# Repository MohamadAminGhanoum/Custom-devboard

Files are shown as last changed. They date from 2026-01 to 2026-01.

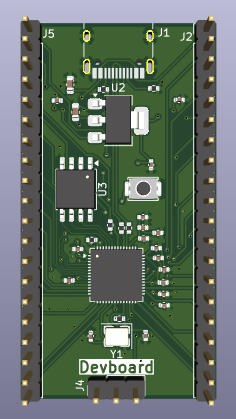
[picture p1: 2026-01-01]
assets/Screenshot 2026-01-01 at 15.13.54.png

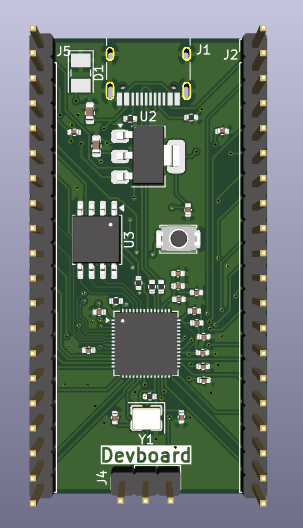
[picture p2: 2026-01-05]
assets/Final 3d model.png

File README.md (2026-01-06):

# Custom-devboard
I will make custom devboard that i can use to create simple projects on my breadboard that do not require soldering. these projects could e.g be make light blink and control simple sensors. 

 

During this hour, i worked on beginning with the set up of schematic. I followed the guide and learned new things, e.g about the decoupling capacitors and how they function in the circuit. I also learned about how the usb-c is connected in a circuit and what the different pins do.



The finished schematic diagram looks like this:



Then i began building and connecting components  pcb i have built:
The pcb i did was the most complex i have done so far, it was soo tricky because of the small space, especially when connecting to the rp2040 mcu. As seen in this picture, it was difficult to conenct som tracks in such a small spacing, so i had to do a lot of changes to achieve the ending result.




But now, i think the more complex part is here, i have 42 errors i should fix This actually takes a lot of time.



I got to fix all vital errors and ended only with the silkscreen crossing the edgecuts, and this error is normal, because i want the usb-c to go past the board-ending, so it does not matter, however the finished look for pcb looks like this:



The BOM:

Screenshot_1-1-2026_204322_docs google com

LCSC Electronics:

Screenshot_5-1-2026_164121_www lcsc com

JLCPCB:



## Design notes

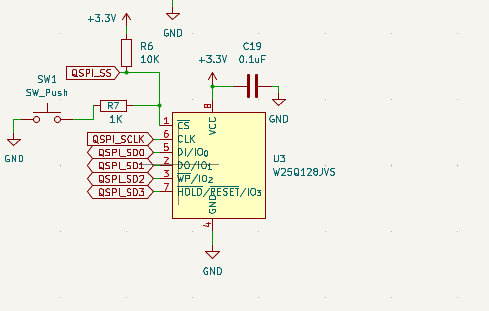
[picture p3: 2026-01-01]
assets/Schematic-4.png

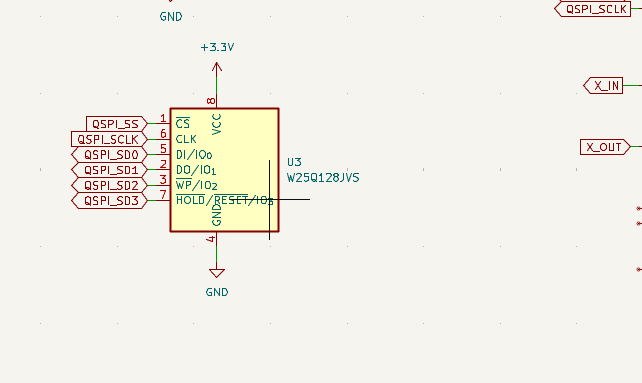
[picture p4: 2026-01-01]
assets/schematic-3.png

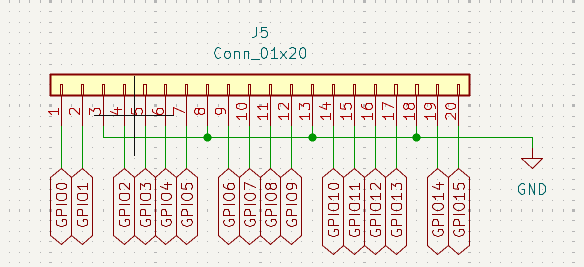
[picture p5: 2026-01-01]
assets/Schematic-7.png

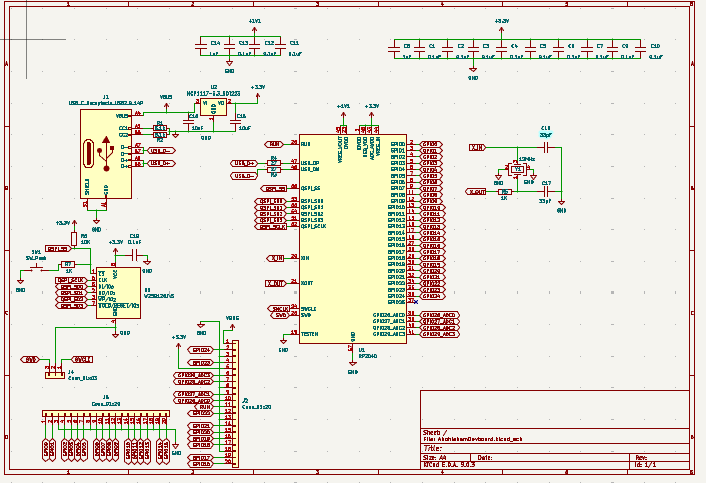
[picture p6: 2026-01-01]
assets/Schematic-8.png

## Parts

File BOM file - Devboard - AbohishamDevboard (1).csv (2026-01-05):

Id | Designator | Footprint | Quantity | Comment | LCSC part: | Quantity from LCSC electronics | Price from LCSC
1 | C19,C3,C10,C4,C11,C1,C12,C7,C5,C2,C13,C6,C9 | C_0402_1005Metric | 13 | 0.1uF | C1525 | 100 | 0.12 USD
2 | C17,C18 | C_0402_1005Metric | 2 | 33pF | C107005 | 100 | 0.11 USD
3 | Y1 | Crystal_SMD_3225-4Pin_3.2x2.5mm | 1 | 12MHz | C9002 | 10 | 0.68 USD
4 | R5,R7 | R_0402_1005Metric | 2 | 1K | C106235 | 100 | 0.07 USD
5 | J2,J5 | PinHeader_1x20_P2.54mm_Vertical | 2 | Conn_01x20 | C50981 | 5 | 0.53 USD
6 | C8,C14 | C_0402_1005Metric | 2 | 1uF | C14445 | 100 | 0.17 USD
7 | U1 | QFN-56-1EP_7x7mm_P0.4mm_EP3.2x3.2mm | 1 | RP2040 | C2040 | 1 | 0.95 USD
8 | R6 | R_0402_1005Metric | 1 | 10K | C60490 | 100 | 0.06 USD
9 | C16,C15 | C_0603_1608Metric | 2 | 10uF | C19702 | 50 | 0.29 USD
10 | R1,R2 | R_0402_1005Metric | 2 | 5.1k | C25905 | 100 | 0.06 USD
11 | J1 | USB_C_Receptacle_HRO_TYPE-C-31-M-12 | 1 | USB_C_Receptacle_USB2.0_14P | C165948 | 5 | 0.88 USD
12 | U3 | SOIC-8_5.3x5.3mm_P1.27mm | 1 | W25Q128JVS | C97521 | 1 | 1.64 USD
13 | R3,R4 | R_0402_1005Metric | 2 | 27ohm | C138021 | 100 | 0.08 USD
14 | J4 | PinHeader_1x03_P2.54mm_Vertical | 1 | Conn_01x03 | C92159 | 20 | 0.37 USD
15 | U2 | SOT-223-3_TabPin2 | 1 | NCP1117-3.3_SOT223 | C26537 | 5 | 1.18 USD
16 | SW1 | SW_Push_SPST_NO_Alps_SKRK | 1 | SW_Push | C202388 | 5 | 0.84 USD
17 | LED | Red LED indicator | 1 | SMD_LED | C19171390 | 100 | 0.57 USD
 | PCB | PCB | 5 | from JLCPCB(4USD) | NA

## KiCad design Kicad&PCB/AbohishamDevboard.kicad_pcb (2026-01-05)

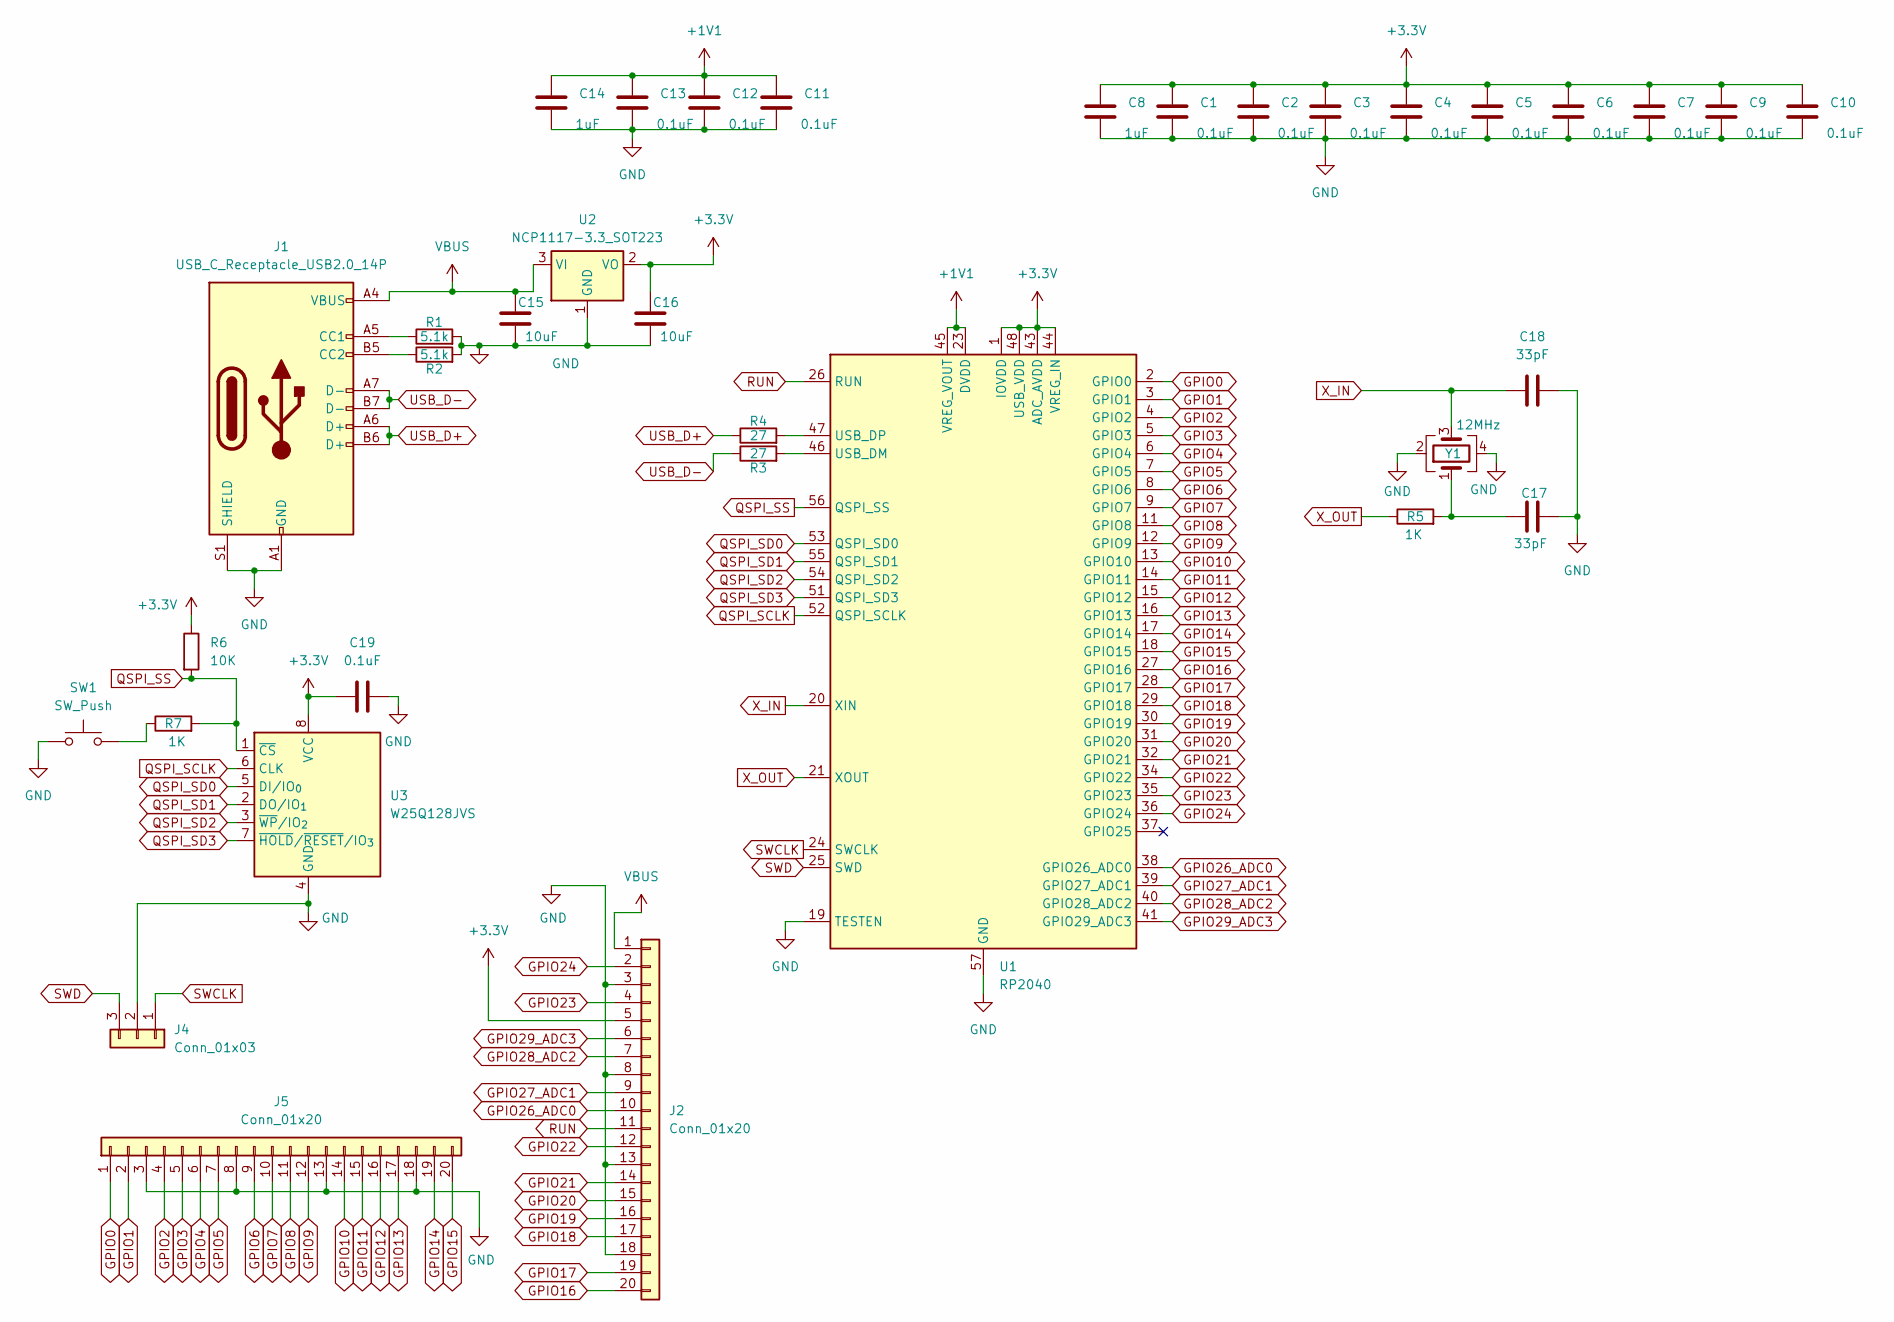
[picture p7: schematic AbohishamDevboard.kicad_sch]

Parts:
C1, C2, C3, C4, C5, C6, C7, C9, C10, C11, C12, C13, C19: 0.1uF; C_0402_1005Metric
C8, C14: 1uF; C_0402_1005Metric
C15, C16: 10uF; C_0603_1608Metric
C17, C18: 33pF; C_0402_1005Metric
J1: USB_C_Receptacle_USB2.0_14P; USB_C_Receptacle_HRO_TYPE-C-31-M-12
J2, J5: Conn_01x20; PinHeader_1x20_P2.54mm_Vertical
J4: Conn_01x03; PinHeader_1x03_P2.54mm_Vertical
R1, R2: 5.1k; R_0402_1005Metric
R3, R4: 27; R_0402_1005Metric
R5, R7: 1K; R_0402_1005Metric
R6: 10K; R_0402_1005Metric
SW1: SW_Push; SW_Push_SPST_NO_Alps_SKRK
U1: RP2040; QFN-56-1EP_7x7mm_P0.4mm_EP3.2x3.2mm
U2: NCP1117-3.3_SOT223; SOT-223-3_TabPin2
U3: W25Q128JVS; SOIC-8_5.3x5.3mm_P1.27mm
Y1: 12MHz; Crystal_SMD_3225-4Pin_3.2x2.5mm

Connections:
+1V1: C11.1, C12.1, C13.1, C14.1, U1.23 (DVDD), U1.45 (VREG_VOUT), U1.50 (DVDD)
+3.3V: C1.1, C2.1, C3.1, C4.1, C5.1, C6.1, C7.1, C8.1, C9.1, C10.1, C16.1, C19.1, J2.5, R6.1, U1.1 (IOVDD), U1.10 (IOVDD), U1.22 (IOVDD), U1.33 (IOVDD), U1.42 (IOVDD), U1.43 (ADC_AVDD), U1.44 (VREG_IN), U1.48 (USB_VDD), U1.49 (IOVDD), U2.2 (VO), U3.8 (VCC); also elsewhere on the board
GND: C1.2, C2.2, C3.2, C4.2, C5.2, C6.2, C7.2, C8.2, C9.2, C10.2, C11.2, C12.2, C13.2, C14.2, C15.2, C16.2, C17.2, C18.2, C19.2, J1.A1 (GND), J1.A12 (GND), J1.B1 (GND), J1.B12 (GND), J1.S1 (SHIELD), J2.3, J2.8, J2.13, J2.18, J4.2, J5.3, J5.8, J5.13, J5.18, R1.2, R2.2, SW1.1, U1.19 (TESTEN), U1.57 (GND), U2.1 (GND), U3.4 (GND), Y1.2, Y1.4; also elsewhere on the board
GPIO0: J5.1, U1.2 (GPIO0)
GPIO1: J5.2, U1.3 (GPIO1)
GPIO2: J5.4, U1.4 (GPIO2)
GPIO3: J5.5, U1.5 (GPIO3)
GPIO4: J5.6, U1.6 (GPIO4)
GPIO5: J5.7, U1.7 (GPIO5)
GPIO6: J5.9, U1.8 (GPIO6)
GPIO7: J5.10, U1.9 (GPIO7)
GPIO8: J5.11, U1.11 (GPIO8)
GPIO9: J5.12, U1.12 (GPIO9)
GPIO10: J5.14, U1.13 (GPIO10)
GPIO11: J5.15, U1.14 (GPIO11)
GPIO12: J5.16, U1.15 (GPIO12)
GPIO13: J5.17, U1.16 (GPIO13)
GPIO14: J5.19, U1.17 (GPIO14)
GPIO15: J5.20, U1.18 (GPIO15)
GPIO16: J2.20, U1.27 (GPIO16)
GPIO17: J2.19, U1.28 (GPIO17)
GPIO18: J2.17, U1.29 (GPIO18)
GPIO19: J2.16, U1.30 (GPIO19)
GPIO20: J2.15, U1.31 (GPIO20)
GPIO21: J2.14, U1.32 (GPIO21)
GPIO22: J2.12, U1.34 (GPIO22)
GPIO23: J2.4, U1.35 (GPIO23)
GPIO24: J2.2, U1.36 (GPIO24)
GPIO26_ADC0: J2.10, U1.38 (GPIO26_ADC0)
GPIO27_ADC1: J2.9, U1.39 (GPIO27_ADC1)
GPIO28_ADC2: J2.7, U1.40 (GPIO28_ADC2)
GPIO29_ADC3: J2.6, U1.41 (GPIO29_ADC3)
unnamed: C17.1, R5.2, Y1.1
unnamed: J1.A5 (CC1), R1.1
unnamed: J1.B5 (CC2), R2.1
unnamed: R7.1, SW1.2
unnamed: R3.2, U1.46 (USB_DM)
unnamed: R4.2, U1.47 (USB_DP)
QSPI_SCLK: U1.52 (QSPI_SCLK), U3.6 (CLK)
QSPI_SD0: U1.53 (QSPI_SD0), U3.5 (DI/IO_{0})
QSPI_SD1: U1.55 (QSPI_SD1), U3.2 (DO/IO_{1})
QSPI_SD2: U1.54 (QSPI_SD2), U3.3 (~WP/IO_{2})
QSPI_SD3: U1.51 (QSPI_SD3), U3.7 (~HOLD/~RESET/IO_{3})
QSPI_SS: R6.2, R7.2, U1.56 (QSPI_SS), U3.1 (~CS)
RUN: J2.11, U1.26 (RUN)
SWCLK: J4.1, U1.24 (SWCLK)
SWD: J4.3, U1.25 (SWD)
USB_D+: J1.A6 (D+), J1.B6 (D+), R4.1
USB_D-: J1.A7 (D-), J1.B7 (D-), R3.1
VBUS: C15.1, J1.A4 (VBUS), J1.A9 (VBUS), J1.B4 (VBUS), J1.B9 (VBUS), J2.1, U2.3 (VI)
X_IN: C18.1, U1.20 (XIN), Y1.3
X_OUT: R5.1, U1.21 (XOUT)

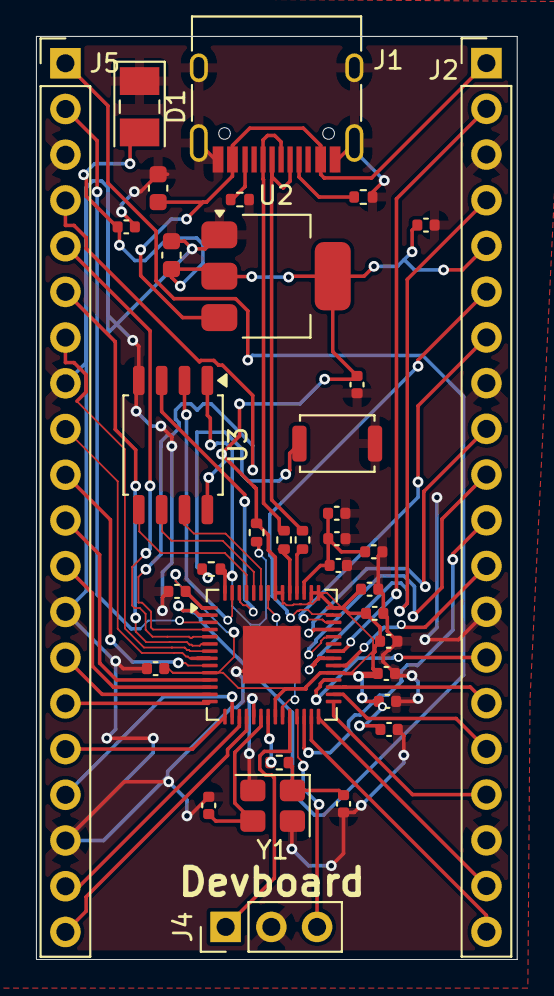
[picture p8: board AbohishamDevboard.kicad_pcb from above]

Board: 2 copper layers, 26.7 x 51.3 mm, 37 parts (1 on the bottom side), 52 nets.

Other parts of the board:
D1: LED; LED_PLCC-2_3x2mm_KA
Devboard: LOGO

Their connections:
+3.3V: D1.2 (A); also elsewhere on the board
GND: D1.1 (K); also elsewhere on the board
